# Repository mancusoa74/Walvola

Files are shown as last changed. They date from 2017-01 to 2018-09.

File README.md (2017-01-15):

# Walvola

Realizzazione sistema di valvole termostatiche per termosifoni casalinghi con controllo remoto wi-fi

[Valvola termostatica TM3030 con controllo wireless](http://mancusoa74.blogspot.it/2017/01/come-aggiungere-il-controllo-wireless.html)  

Questo progetto e' formato da 3 parti principali:

**Hardware**

* [Progetto](https://github.com/mancusoa74/Walvola/tree/master/Hardware) Fritzing del controller della valvola basato su ESP8266-01 e ESP8266-12

**Software**

* [**Walvola**](https://github.com/mancusoa74/Walvola/tree/master/Software/Walvola): software di gestione della valvola che gira su ESP8266-01 - ESP8266-12
* [**iHeating**](https://github.com/mancusoa74/Walvola/tree/master/Software/iHeating): semplice web application basata su Framework7 per controllo valvole

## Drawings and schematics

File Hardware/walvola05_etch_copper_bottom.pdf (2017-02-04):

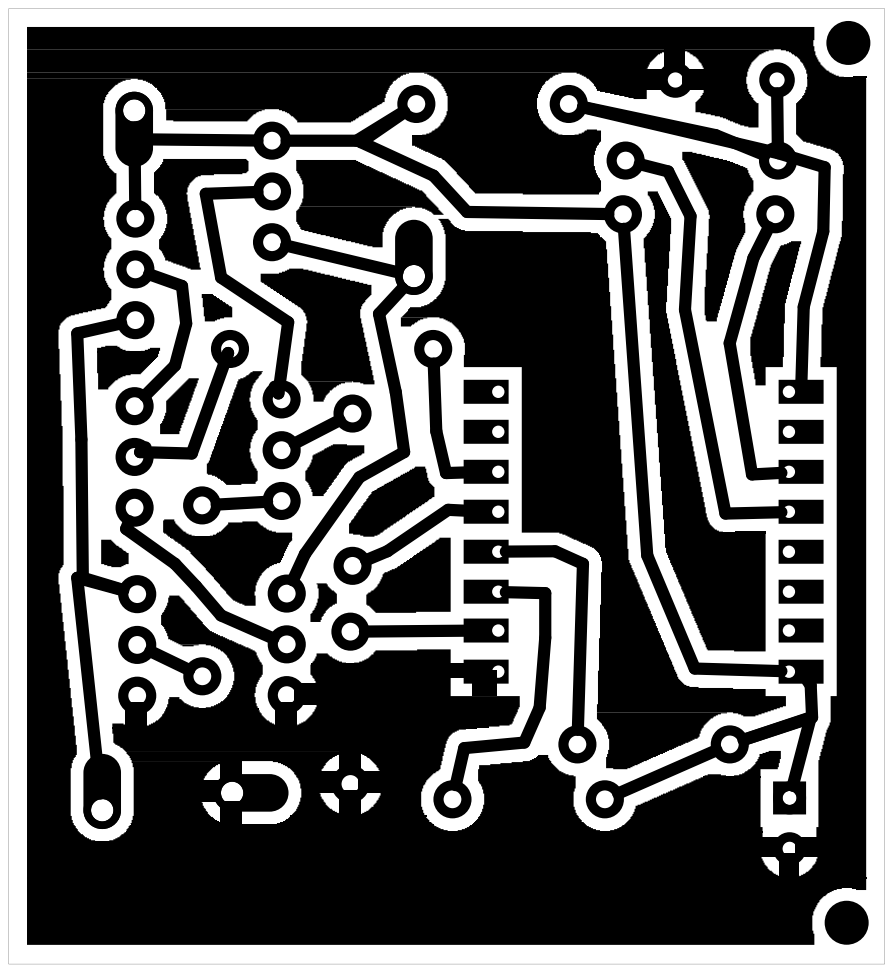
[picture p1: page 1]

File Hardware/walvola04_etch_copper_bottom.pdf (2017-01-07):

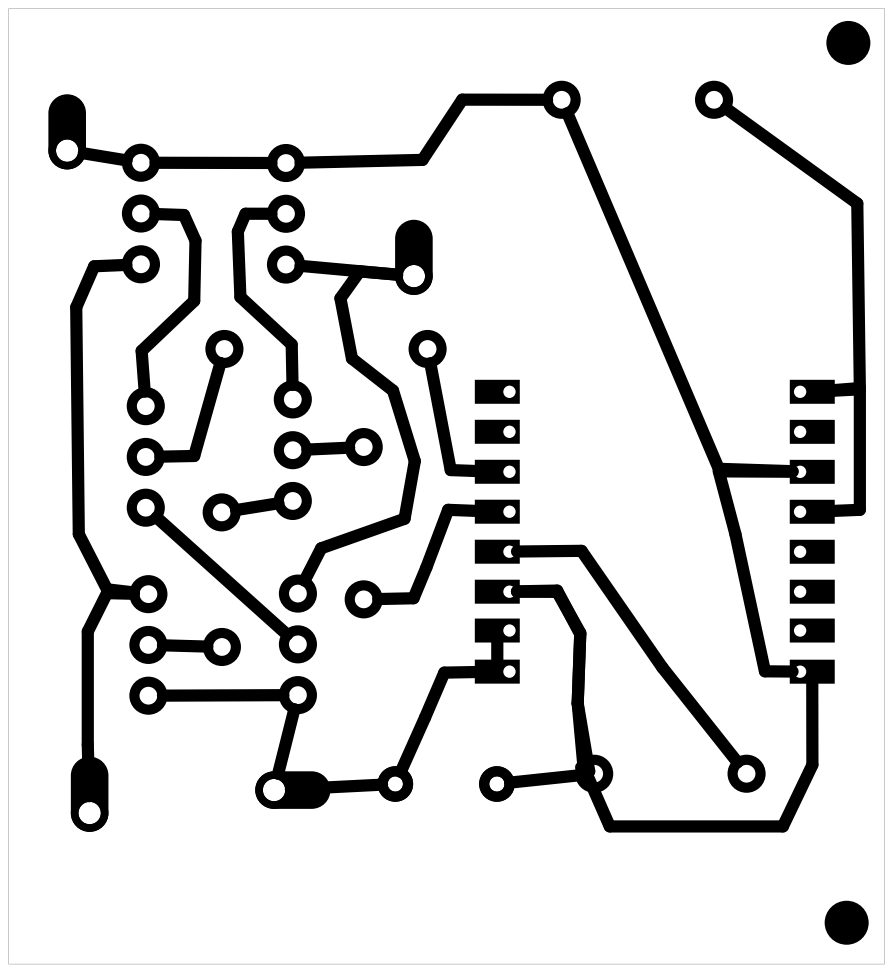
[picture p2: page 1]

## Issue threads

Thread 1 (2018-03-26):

Walvola 05 - Stabilità deep sleep

marco-gallinari, 2018-03-26:
Buongiorno Antonio,

come già condiviso sul suo blog, sto prendendo spunto dal suo ottimo lavoro per realizzare qualcosa di simile per il mio appartamento.

Uno dei componenti del progetto è un box di sensorizzazione con alimentazione a batterie ricaricabili e con cicli di deep sleep di 15 minuti.

Ho notato una certa instabilità del ciclo di deep sleep; dopo qualche ora di funzionamento con cicli di test da 3 minuti, il modulo esp8266 sembra bloccarsi, e per farlo riprendere devo resettare l'alimentazione al componente.

Sto indagando per capire l'origine del problema, e ho notato che la versione 5 dell'hardware Walvola sono state integrate delle modifiche proprio alla connessione RST - GPIO16, immagino proprio per aumentarne la stabilità.

Posso chiederle maggiori delucidazioni a riguardo? Dallo schema non mi è chiaro il motivo per cui sono state apportate le modifiche.

Grazie,
Marco

mancusoa74, 2018-03-26:
se hai problemi con il deep sleep assicurati di avere una buona alimentazione del ESP8266

puoi ispirarti a questo

https://raw.githubusercontent.com/nodemcu/nodemcudevkit/master/Documents/NODEMCU_DEVKIT_SCH.png

il condensatore fa si che il reset sia un pochino piu' lungo per essere sicuri che il pin RST senta il segnale da GPIO16.

per esempio nel mio caso della walvola ho il problema che alimento sotto i 3V3 e questo rende deep sleep instabile.

se puoi usare un nodeMCU nel tuo progetto (se hai spazio) risolvi molti problemi legati all'alimentazione e RST

ciao
Antonio

marco-gallinari, 2018-03-26:
Grazie mille!

L'immaginemi  chiarisce anche tante cose che avevo dedotto da vari forum, non l'avevo ancora vista.

L'utilizzo della nodeMCU non l'ho escluso, ma vorrei tenerlo come "piano B" per via sia dello spazio che dei consumi.

Closed 2018-03-26.

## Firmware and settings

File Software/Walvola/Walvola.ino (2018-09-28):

 /*
#Author:   Antonio Mancuso
#Purpose:  Walvola: code to run on any SMHA esp8266-01/12 module. This code can impersonate different roles

#Version   2.0.0 - summer 2017 - adding WAC support
#Version:  1.5.2 - 11/02/2017 - adding reset after deep sleep
#Version:  1.5.1 - 05/02/2017 - fixing telegram notification (28% 295513 and 58% 48168 are needed for telegram to work SSL certificate)
#Version:  1.5   - 04/02/2017 - control eeprom use trhough define - wifi disable during motor action to save energy
#Version:  1.4.1 - 22/01/2017 - fixing time calculation
#Version:  1.4   - 21/01/2017 - replacing  www.timeapi.org as this service is not available anymore   
#Version:  1.3   - 11/01/2017 - clean up for publishing on github - Teleram disbale due to some issue with SSL https://github.com/espressif/ESP8266_MESH_DEMO/issues/19 - https://github.com/esp8266/Arduino/issues/1375
#Version:  1.2   - 24/12/2016 - adding OTA support
#Version:  1.1   - 08/12/2016 - intrducing deep_sleep mode
#Version:  1.0   - 01/12/2016 - adding dynamic WALVOLA_SLEEP_PERIOD and WALVOLA_SLEEP_DELAY based on time of the day
#Version:  0.9   - 27/11/2016 - switching to mutiple queues model
#Version:  0.8   - 24/11/2016 - code refactoring
#Version:  0.7   - 20/11/2016 - Adding WiFi OFF period
#Version:  0.6   - 13/11/2016 - Switching to CloudMQTT as PubNub looks like is not working anymore and adding voltage post to Keen.io
#Version:  0.5   - 06/11/2016 - Adding Telegram Bot support
#Version:  0.4   - 04/11/2016 - Adding support for IRB
#Version:  0.3   - 18/09/2016 - Removal of ArduinoJson library and manual JSON parsing
#Version:  0.2   - 18/09/2016 - clean up and MQTT message processing logic
*/

#include "Walvola.h"

/*
 * =========== Global variables to configure behavior ===========
*/
//const PROGMEM String keen_voltage_collection = "YOUR KEEN.IO VOLTAGE COLLECTION" + String(WALVOLA_LABEL); //I post voltage value to a https://keen.io collection for statistics and chart
const String keen_voltage_collection = "YOUR KEEN.IO VOLTAGE COLLECTION" + String(WALVOLA_LABEL); //I post voltage value to a https://keen.io collection for statistics and chart

//unsigned long walvola_sleep_period = WALVOLA_DEFAULT_SLEEP_PERIOD;
String walvola_time                  = "1970-01-01--00-00-00"; //default time in honor of Unix
boolean inet_connected               = false; //track whether connected to Internet or not
boolean update_mode                  = false; //track whether the walvola is in OTA update mode
unsigned long last_schedule          = millis();

void setup()
{
        // Setup Serial Console only in DEBUG mode
        if (DEBUG){ 
                Serial.begin(SERIAL_SPEED);
                delay(SERIAL_INIT_DELAY);
                log(" ");
                log("Walvola Software " + String(VERSION) + " starting ..........");
                log(mqtt_client_id);
        }

//        enum rst_reason {
//                REASON_DEFAULT_RST              = 0,    /* normal startup by power on */
//                REASON_WDT_RST                  = 1,    /* hardware watch dog reset */
//                REASON_EXCEPTION_RST    = 2,    /* exception reset, GPIO status wonâ€™t change */
//                REASON_SOFT_WDT_RST     = 3,    /* software watch dog reset, GPIO status wonâ€™t change */
//                REASON_SOFT_RESTART     = 4,    /* software restart ,system_restart , GPIO status wonâ€™t change */
//                REASON_DEEP_SLEEP_AWAKE = 5,    /* wake up from deep-sleep */
//                REASON_EXT_SYS_RST      = 6             /* external system reset */
//        };

//        #if defined(WALVOLA_ROLE) || defined(WAC_ROLE)
//            rst_info *rinfo = ESP.getResetInfoPtr();
//            log(String("ResetInfo.reason = ") + (*rinfo).reason); 
//            if ((*rinfo).reason == REASON_DEEP_SLEEP_AWAKE) {
//                    log("boot from deep sleep --> reset") ;
//                    ESP.restart() ;
//            }
//        #endif

        // walvola should maintain the status (ON/OFF) as it a battery powered device. in case battery discharges the status of walvola is not changing as the motor is not spinning
        // irb is driving a relay,so in case power is removed the relay switch back to normal position and status reset so we don't need to keep status for it
        #if defined(WALVOLA_ROLE) || defined(WAC_ROLE)
        #if EEPROM_ENABLE == 1
                eeprom_init();
        

                //get the status of walvola in eeprom and if not set, set it to WALVOLA_ON (default status of walvola)
                if ((walvola_status = get_eeprom_walvola_status()) == "EEPROM_NOT_SET") {
                        log("eeprom walvola status not set.... initializing it");
                        walvola_status = WALVOLA_ON;
                        set_eeprom_walvola_status(walvola_status);
                }

                log("Inital Walvola Status = ");
                log(walvola_status);
        #endif
        #endif

        //basic initialization of the two GPIO pins used by Walvola and IRB
        GPIO_init();
        
        //this is the main code executed for device in DEEP_SLEEP_MODE as loop will be empty
        //in my setup walvola is ESP8266-12 so I use deep sleep
        #ifdef WALVOLA_DEEP_SLEEP_MODE
                log("DEEP SLEEP MODE");

                //the following chuck of code performs the following tasks
                //1- connect to wifi if not connected
                //2- retrieve web time (no needs for RTC when you have Internet :) )
                //3- initialize connection to MQTT broker
                //4- check if MQTT message is available and process it
                if (WiFi.status() != WL_CONNECTED) {
                        log("WiFi connecting...");
                        log("start_inet_connectivity(true)");  
                        start_inet_connectivity(true);  
                }

                // get voltage from power source and post it to https://keen.io service
                log("KEEN VOLTAGE");
                keen_voltage();

                //tgram_sendmex("telegram sent"); 
                
                //if devie is NOT in OTA_MODE goes to deep_sleep for WALVOLA_DEFAULT_DEEP_SLEEP_PERIOD seconds
                if (!update_mode) {
//                        stop_inet_connectivity();
//                        delay(5000);
                        log("going to DEEP SLEEP");
                        ESP.deepSleep(WALVOLA_DEFAULT_DEEP_SLEEP_PERIOD * 1000000);
                        delay(500); //candidate to go into 1.4.2
                } 
                
                log("Entering OTA mode...");
        #endif
}

void loop()
{
        //if device is in OTA_MODE let's handle client request
        #ifdef OTA_MODE
                httpServer.handleClient();
        #endif

        //this is the main code executed for device in MODEM_SLEEP_MODE
        //in my setup walvola is ESP8266-01 so I use modem sleep
        //most of the logic is the same as for deep sleep
        #ifdef WALVOLA_MODEM_SLEEP_MODE
                if (millis() > (last_schedule  + WALVOLA_DEFAULT_SLEEP_PERIOD)) {
                        if (WiFi.status() != WL_CONNECTED) {
                                log("WiFi connecting...");
                                log("start_inet_connectivity(true)");  
                                start_inet_connectivity(true);
                        }

                        keen_voltage();
                        last_schedule = millis();

                        //to increase the duration of batteries during night time the sleep time is increased to 4 hrs
                        //walvola_sleep_period = dynamic_sleep_period();

                        //log("Calculated dynamic walvola sleep time is:");
                        //log(walvola_sleep_period);
                } else {
                        if (WiFi.status() == WL_CONNECTED) {
                                log("WiFi disconnecting...");
                                stop_inet_connectivity(); 
                        }
                        log("sleeping...");
                        delay(WALVOLA_SLEEP_DELAY);
                        //delay(walvola_sleep_period);
                }
        #endif
}

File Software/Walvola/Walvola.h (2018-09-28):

/*
#Author:   Antonio Mancuso
#Purpose:  Walvola: code to run on any SMHA esp8266-01 module. This code can impersonate different roles
*/

#ifndef WALVOLA_H
#define WALVOLA_H

extern "C"
{
        #include "user_interface.h"
}


#include <Arduino.h>
#include <FujitsuHeatpumpIR.h>
#include <WiFiClient.h>
#include <WiFiClientSecure.h>
#include <ESP8266WiFi.h>
#include <ESP8266HTTPClient.h>
#include <ESP8266WebServer.h>
#include <ESP8266mDNS.h>
#include <ESP8266HTTPUpdateServer.h>
//#include <ESPTelegramBot.h>
#include <MQTT.h>
#include <PubSubClient.h>
#include <jsmn.h> //https://github.com/zserge/jsmn
#include <Arduino.h>
#include <pgmspace.h>
#include "keen.h"
#include "misc.h"
#include "telegram.h"
#include "json.h"
#include "wifi.h"
#include "mqtt.h"
#include "timeapi.h"

/*
 * =========== Global defines to configure behavior ===========
*/

#define WALVOLA_DEEP_SLEEP_MODE  //uncomment to enable deep sleep mode
//#define WALVOLA_MODEM_SLEEP_MODE //uncomment to enable modem sleep mode
//#define WALVOLA_ROLE             //code behaves as a Walvola http://mancusoa74.blogspot.it/2017/01/come-aggiungere-il-controllo-wireless.html
//#define IRB_ROLE                 //code behaves as a IRB http://mancusoa74.blogspot.it/2015/11/internet-relay-board-v2.html
#define WAC_ROLE
#define OTA_MODE                 //uncomment to enable OTA software upgrade http://esp8266.github.io/Arduino/versions/2.0.0/doc/ota_updates/ota_updates.html#web-browser

#define DEBUG              0           //1=enable DEBUG mode; 0=disble debug mode
#define MQTT_DEBUG         0           //1=enable MQTT DEBUG mode; 0=disble MQTT debug mode; post debug message to a /debug topic
#define EEPROM_ENABLE      1           //1=enable storage of status in EEPROM; 0=disable for debug with short sleep period
#define VERSION            "v2.0.0(00002)" 
#define SERIAL_SPEED       115200
#define SERIAL_INIT_DELAY  10
#define WALVOLA_DELAY_ON   35000       //time (ms) for which the walvola motor is activated to open the walvola
#define WALVOLA_DELAY_OFF  35000       //time (ms) for which the walvola motor is activated to close the walvola
#define WALVOLA_LABEL      "YOUR UNIQUE VALVOLA NAME"   //walvola name which is shown on mobile APP
#define WALVOLA_ID         "wac02" //unique id of the walvola. it is used to define MQTT topic for communications with mobile app

#if DEBUG == 0
  #define WALVOLA_DEFAULT_DEEP_SLEEP_PERIOD 900 //deep sleep period in seconds (15 minutes)
  #define WALVOLA_DEFAULT_SLEEP_PERIOD 600000L  //modem sleep perion in ms (10 minutes) 
  #define WALVOLA_SLEEP_DELAY 300000            //loop delay in ms
#else
  #define WALVOLA_DEFAULT_DEEP_SLEEP_PERIOD 15  //debug
  #define WALVOLA_DEFAULT_SLEEP_PERIOD 10000L   //debug
  #define WALVOLA_SLEEP_DELAY 500 //debug
#endif

#define WALVOLA_NIGHT_SLEEP_PERIOD 18000000L   //night modem sleep period (5 hrs)

extern String walvola_time;
extern boolean inet_connected;
extern boolean update_mode;

//---------- SUPPORT MACRO AND DEFINITION ----------
//#define log(mex) if (DEBUG) {Serial.println(walvola_time + "::" + mex);Serial.flush(); if(MQTT_DEBUG) {mqtt_log(walvola_time + "::" + mex);}}
#define log(mex) if (DEBUG) {Serial.println(walvola_time + "::" + mex);Serial.flush();}

#endif

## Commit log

2017-01-07 adding fritzing project
    [walvola04.fzz]
2017-01-15 update of README
    [walvola04.fzz]
2017-01-15 adding Hardware section
    [walvola04.fzz]
2017-01-22 v.1.4.1: fixing time management
    [Walvola.h, Walvola.ino]
2017-02-04 v1.5 wifi off during motor action to save energy
2017-02-04 walvola HW v5. improved stability on dep sleep wakeup
    [walvola05.fzz]
